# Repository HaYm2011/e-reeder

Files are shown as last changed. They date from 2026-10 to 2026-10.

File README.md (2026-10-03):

# e-reeder
a e-reader... aka chapri kindle

reeder

## Bill of Materials (BOM)

| Item | Component | Vendor | Unit Price (INR) | Qty | Total Price (INR) | Purpose / Notes |
| :--- | :--- | :--- | :---: | :---: | :---: | :--- |
| 1 | [4.3" Serial Interface Electronic Paper Display](https://robocraze.com/products/4-3in-serial-interface-electronic-paper-display) | Robocraze | ₹4,699.00 | 1 | ₹4,699.00 | 800×600 UART e-paper screen |
| 2 | [7Semi ESP32-S3 Dev Board (N8R8, Dual Type-C)](https://robocraze.com/products/7semi-esp32-s3-dev-boardc-1-n8r8-wifi-bluetooth-dual-usb-c-rgb-led) | Robocraze | ₹899.00 | 1 | ₹899.00 | Primary microcontroller (8MB Flash, 8MB PSRAM) |
| 3 | [VL53L0X TOF Laser Distance Sensor](https://robu.in/product/vl53l0x-tof-based-lidar-laser-distance-sensor/) | Robu.in | ₹119.00 | 2 | ₹238.00 | Left & right gesture detection for page turns |
| 4 | [3.7V 2000mAh 18650 Li-Ion Battery](https://robocraze.com/products/3-7v-2000mah-18650-li-ion-battery) | Robocraze | ₹69.00 | 3 | ₹207.00 | Rechargeable battery cells |
| 5 | [18650 3-Cell Holder Without Cover](https://robocraze.com/products/18650-3-cell-holder-charger-without-cover) | Robocraze | ₹33.00 | 1 | ₹33.00 | Series enclosure/leads for 3× 18650 cells |
| 6 | Custom 3D Printed Enclosure:  https://robu.in/product/3d-printing-service1/ | Robocraze 3d-printing service | ₹700.00 | 1 | ₹700.00 | Front & back shell housing |
| **Total** | | | | **9** | **₹6,776.00** | *(Excluding shipping)* |

for the 3d print i have checked the cost of printing it with 0.2 standard quality 20% infil PLA(black): it amounts to ₹700




allreeder
schreeder
pcbreeeder




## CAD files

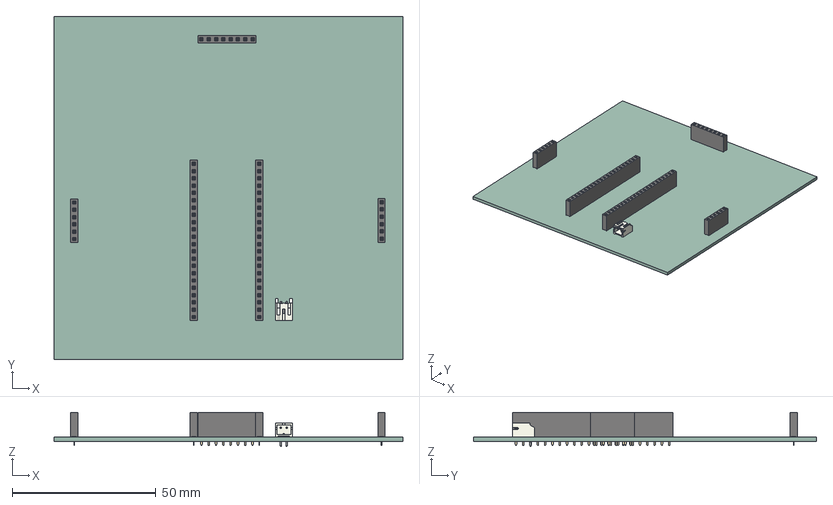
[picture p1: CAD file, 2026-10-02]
e-reeder.step
121.5 x 119.5 x 11.9 mm
PinSocket_1x06_P2.54mm_Vertical x 2
PinSocket_1x08_P2.54mm_Vertical
PinSocket_1x22_P2.54mm_Vertical x 2
JST_PH_S2B-PH-K_1x02_P2.00mm_Horizontal
e-reeder_PCB

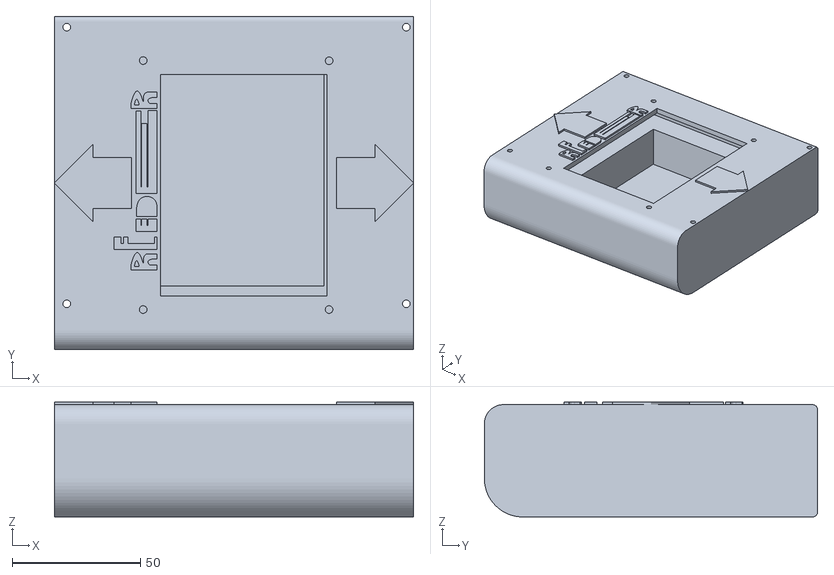
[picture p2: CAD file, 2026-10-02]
reederfinal.stl
140.0 x 130.0 x 44.8

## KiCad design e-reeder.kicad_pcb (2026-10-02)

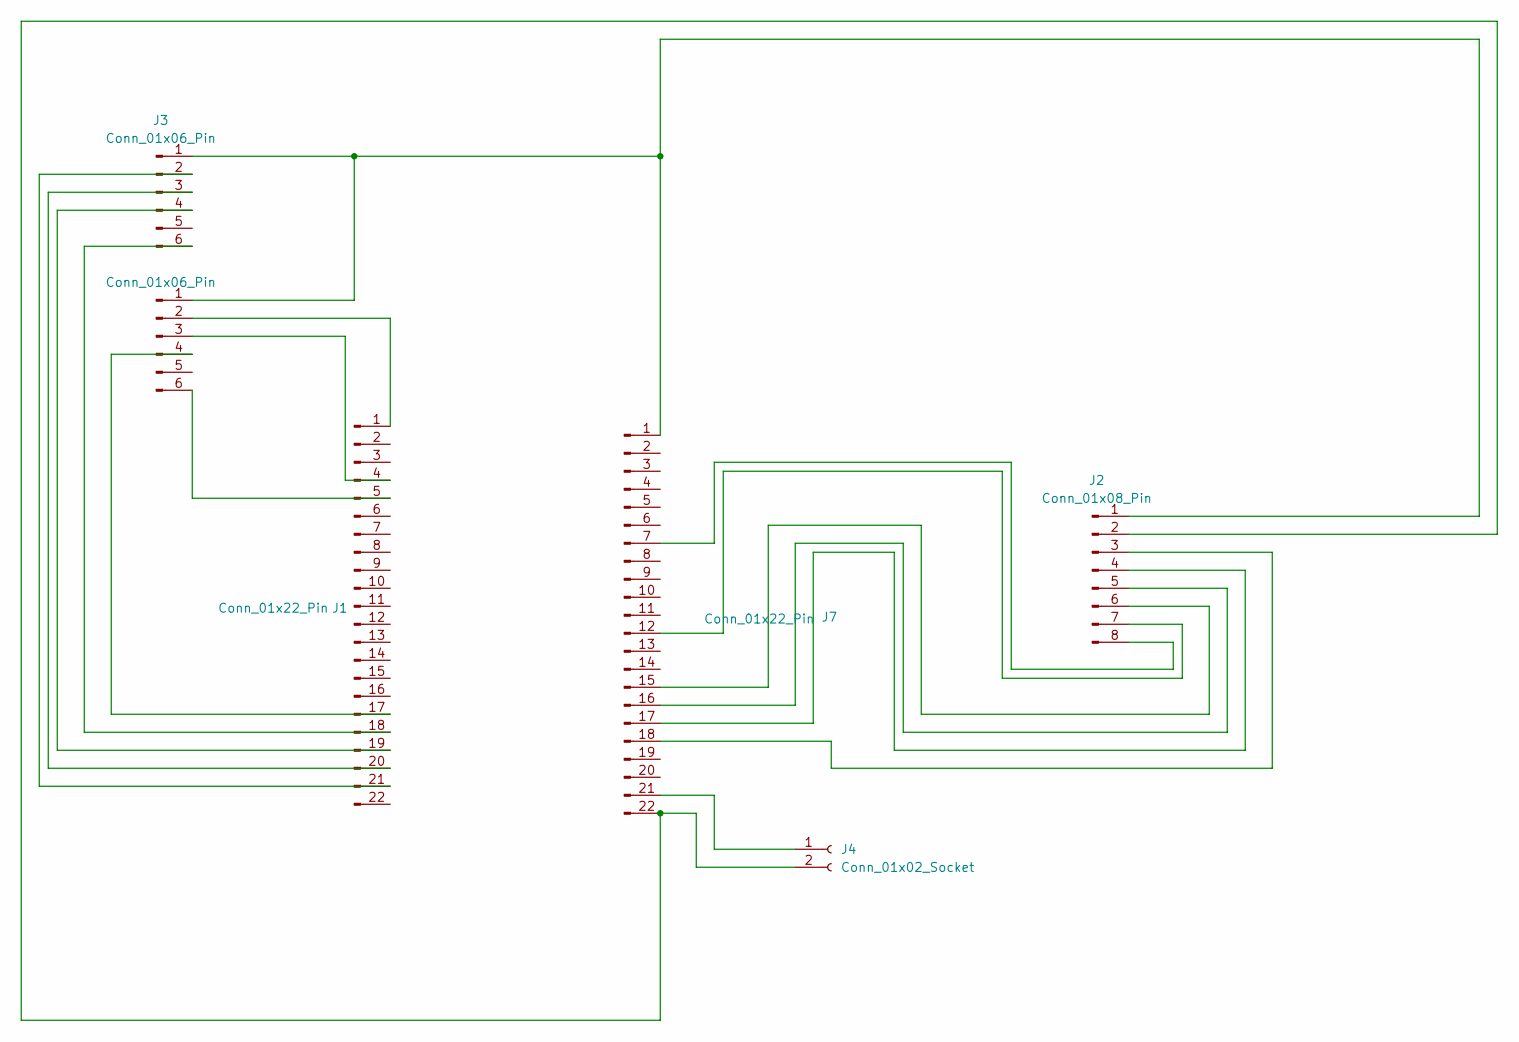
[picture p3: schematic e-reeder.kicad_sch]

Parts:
J1, J7: Conn_01x22_Pin; PinSocket_1x22_P2.54mm_Vertical
J2: Conn_01x08_Pin; PinSocket_1x08_P2.54mm_Vertical
J3, J5: Conn_01x06_Pin; PinSocket_1x06_P2.54mm_Vertical
J4: Conn_01x02_Socket; JST_PH_S2B-PH-K_1x02_P2.00mm_Horizontal

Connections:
unnamed: J1.1, J5.2
unnamed: J1.4, J5.3
unnamed: J1.5, J5.6
unnamed: J1.17, J5.4
unnamed: J1.18, J3.6
unnamed: J1.19, J3.4
unnamed: J1.20, J3.3
unnamed: J1.21, J3.2
unnamed: J2.1, J3.1, J5.1, J7.1
unnamed: J2.2, J4.2, J7.22
unnamed: J2.3, J7.18
unnamed: J2.4, J7.17
unnamed: J2.5, J7.16
unnamed: J2.6, J7.15
unnamed: J2.7, J7.12
unnamed: J2.8, J7.7
unnamed: J4.1, J7.21

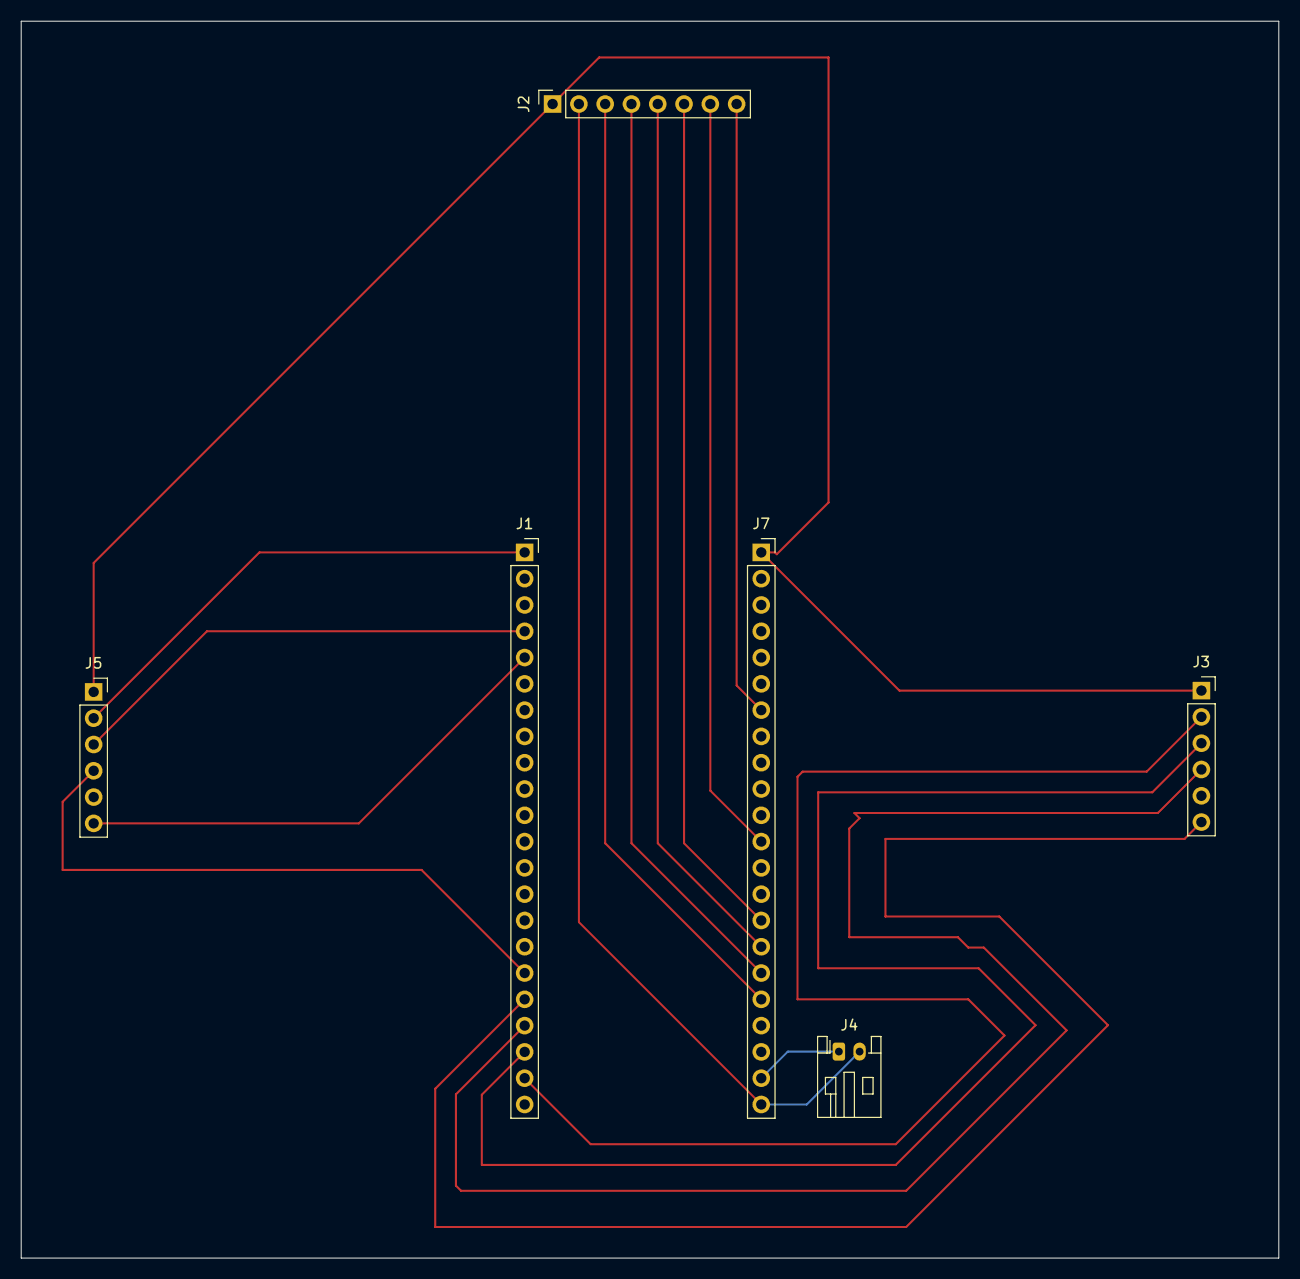
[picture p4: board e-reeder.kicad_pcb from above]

Board: 2 copper layers, 121.5 x 119.5 mm, 6 parts (0 on the bottom side), 17 nets.

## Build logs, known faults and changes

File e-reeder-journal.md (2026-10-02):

# e-reeder

a e-reader... aka chapri kindle

# 2026-10-02: finished up the repo added a BOM

**Total time spent: 0.20 hours**

finished the repo updated the README, added all the project files, the chassis stl. the kicad files and added a BOM 


# 2026-10-02: Finished the chassis of the reeder 

**Total time spent: 1 hour 13 mins**

i finished the design of the chassis of the reeder, i had sm trouble with the battery and i decided ill manually put holes for it while assembling the hardware and the rest of the stuff snaps right in place and use 3mm screws to fix it up together




2026-06-08: made the repository

**Total time spent: 0.20 hours**

made a repo :https://github.com/HaYm2011/e-reeder and added the journal.md im going to add the case step files and the kicad files a bit later


# 2026-06-08: worked a bit on the case

**Total time spent: 0.10 hours**

found a .step file for the batteries and for the sensors
im gonna start with the case for the reeder in the next entry


# 2026-06-04: Started the design

**Total time spent: 1 hour**

got the step file for the pcb ran into a few errors like with the step file and found a good f3d file for the display module . im going to start the design for the chassis in the next entry



# 2026-06-04: added the battery source i forgot about😅

**Total time spent: 0.30 hours**

So i just realised i completely forgot about the battery stuff and i had to go back to the .sch add a JST socket retrace a few copper lines and i think about done with the pcb for real this time





# 2026-06-03: Finished the PCB!!!!!!!!

**Total time spent: 6 hours**

So i finished all the pcb part i was stuck on finding the footprints for all my components for quite a while and then i realised i had to go back to the .sch file for assigning the footprints and i happened to put the male connector footprint instead of the female connector for the esp32 s3 and the sensors. I then did the copper tracing and i had to fix a few overlays in the .sch file and i finally reviewed my progress in the 3d viewer and i had to figure out how to use the measure tool and the move tool at the same time in kicad(i just figured to enter the x,y coords for the components...)

Screenshot 2026-06-03 114855.png

Screenshot 2026-06-03 203839.png

Screenshot 2026-06-03 203854.png

# 2026-05-29: so i finished the pcb schematics (and did a few other stuff)

**Total time spent: 6 hours**

i finished the schematics i changed the e-ink module im gonna be using to:

Waveshare 4.2-inch e-Ink Paper Display Module with SPI Interface:

https://robu.in/product/4-2-inch-e-ink-paper-display-module-with-spi-interface/

this module is essentially the same thing but 0.1 inches lesser than the previous one i selected but this is gonna be easier for me to connect to my esp32 s3.

regarding the pcb schematics i faced quite a few problems since its been a long time since i last used kicad so i forgot that im not supposed to overlay the wires and i spent about a hour rerouting everything and realised that the xshut pins of the VL53L0X TOF Laser Distance Sensors could not be connected to pins like 48 of the esp32 s3 so i rerouted these pins.

i also spent quite a while replacing the older display connections with the newer ones 




# 2026-05-27: research, and making of BOM 

**Total time spent: 5hrs**

So i read about a few other opensource e-reader projects , like this one:

https://github.com/joeycastillo/The-Open-Book

so i realised id like to use a microcontroller for this rather than a micro controller and hence an esp32-s3 for this and a e-ink display i found on robocraze.com :

e-ink module:

https://robocraze.com/products/4-3in-serial-interface-electronic-paper-display?_pos=1&_sid=8128a620e&_ss=r

esp32 s3:

https://robocraze.com/products/7semi-esp32-s3-dev-boardc-1-n8r8-wifi-bluetooth-dual-usb-c-rgb-led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

so i decided im gonna 3d print the frame and add a really compact ToF sensor on each side of the reeder and so when any side detects movement the page is flipped respectively 

VL53L0X TOF Laser Distance Sensor:

https://robu.in/product/vl53l0x-tof-based-lidar-laser-distance-sensor/

for the body of this thing im going to design it and 3d print it



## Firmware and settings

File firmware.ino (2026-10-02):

#include <Wire.h>
#include <Adafruit_VL53L0X.h>

#define I2C_SDA_PIN       8
#define I2C_SCL_PIN       9

#define SENSOR_LEFT_XSHUT  4
#define SENSOR_RIGHT_XSHUT 5

#define EPD_RX_PIN        18
#define EPD_TX_PIN        17
#define EPD_WAKE_PIN      16
#define EPD_RST_PIN       15

HardwareSerial EPD_Serial(1);

#define ADDR_SENSOR_LEFT   0x30
#define ADDR_SENSOR_RIGHT  0x31

Adafruit_VL53L0X sensorLeft  = Adafruit_VL53L0X();
Adafruit_VL53L0X sensorRight = Adafruit_VL53L0X();

#define FRAME_HEADER      0xA5
#define CMD_HANDSHAKE     0x00
#define CMD_SET_BAUD      0x01
#define CMD_READ_BAUD     0x02
#define CMD_SET_MEMORY    0x07
#define CMD_ENTER_STOP    0x08
#define CMD_UPDATE        0x0A
#define CMD_SET_FONT_EN   0x1E
#define CMD_DISP_STRING   0x30
#define CMD_CLEAR         0x2E

#define FONT_ASCII32      0x01
#define FONT_ASCII48      0x02
#define FONT_ASCII64      0x03

#define GESTURE_TRIGGER_MIN_MM  30
#define GESTURE_TRIGGER_MAX_MM  140
#define GESTURE_COOLDOWN_MS     1200

unsigned long lastPageTurnTime = 0;
int currentPage = 0;

const int TOTAL_PAGES = 4;
const char* bookPages[TOTAL_PAGES] = {
  "Project Gutenberg E-Book\n\nChapter 1\nThe cold silence of deep space was interrupted only by the steady hum of life support systems...",
  "Chapter 1 (Cont.)\n\nHe checked the navigation telemetry. The trajectory remained locked towards the distant orbital gate.",
  "Chapter 2\n\nThe sensors pinged a rhythmic anomaly 200 kilometers off the port bow. Something was tracking their velocity profile.",
  "End of Preview.\n\nSwipe left to return to previous pages or restart the demonstration."
};

void epdSendPacket(uint8_t cmd, const uint8_t *payload, uint16_t length) {
  uint16_t frameLen = 1 + 2 + 1 + length + 4 + 1;
  uint8_t buffer[frameLen];
  
  buffer[0] = FRAME_HEADER;
  buffer[1] = (frameLen >> 8) & 0xFF;
  buffer[2] = frameLen & 0xFF;
  buffer[3] = cmd;
  
  for (uint16_t i = 0; i < length; i++) {
    buffer[4 + i] = payload[i];
  }
  
  uint16_t tailIndex = 4 + length;
  buffer[tailIndex++] = 0xCC;
  buffer[tailIndex++] = 0x33;
  buffer[tailIndex++] = 0xC3;
  buffer[tailIndex++] = 0x3C;
  
  uint8_t parity = 0;
  for (uint16_t i = 0; i < tailIndex; i++) {
    parity ^= buffer[i];
  }
  buffer[tailIndex] = parity;
  
  EPD_Serial.write(buffer, frameLen);
  EPD_Serial.flush();
  delay(20);
}

void epdClearScreen() {
  epdSendPacket(CMD_CLEAR, NULL, 0);
}

void epdRefresh() {
  epdSendPacket(CMD_UPDATE, NULL, 0);
}

void epdSetEnFont(uint8_t font) {
  uint8_t data[1] = { font };
  epdSendPacket(CMD_SET_FONT_EN, data, 1);
}

void epdDisplayString(int16_t x, int16_t y, const char *str) {
  uint16_t strLen = strlen(str);
  uint16_t payloadLen = 4 + strLen + 1;
  uint8_t payload[payloadLen];
  
  payload[0] = (x >> 8) & 0xFF;
  payload[1] = x & 0xFF;
  payload[2] = (y >> 8) & 0xFF;
  payload[3] = y & 0xFF;
  
  memcpy(&payload[4], str, strLen);
  payload[4 + strLen] = 0x00;
  
  epdSendPacket(CMD_DISP_STRING, payload, payloadLen);
}

void renderCurrentPage() {
  Serial.printf("Rendering Page %d of %d...\n", currentPage + 1, TOTAL_PAGES);
  
  epdClearScreen();
  epdSetEnFont(FONT_ASCII32);
  
  char headerBuf[32];
  snprintf(headerBuf, sizeof(headerBuf), "--- OpenBook S3 | Page %d/%d ---", currentPage + 1, TOTAL_PAGES);
  epdDisplayString(40, 30, headerBuf);
  
  char tempBuffer[512];
  strncpy(tempBuffer, bookPages[currentPage], sizeof(tempBuffer));
  
  char *line = strtok(tempBuffer, "\n");
  int yOffset = 100;
  
  while (line != NULL && yOffset < 540) {
    epdDisplayString(40, yOffset, line);
    yOffset += 45;
    line = strtok(NULL, "\n");
  }
  
  epdRefresh();
}

void setupToFSensors() {
  pinMode(SENSOR_LEFT_XSHUT, OUTPUT);
  pinMode(SENSOR_RIGHT_XSHUT, OUTPUT);
  
  digitalWrite(SENSOR_LEFT_XSHUT, LOW);
  digitalWrite(SENSOR_RIGHT_XSHUT, LOW);
  delay(20);
  
  digitalWrite(SENSOR_LEFT_XSHUT, HIGH);
  delay(20);
  if (!sensorLeft.begin(ADDR_SENSOR_LEFT, false, &Wire)) {
    Serial.println("Error: Failed to init Left VL53L0X!");
  } else {
    Serial.println("Left VL53L0X active at 0x30");
  }
  
  digitalWrite(SENSOR_RIGHT_XSHUT, HIGH);
  delay(20);
  if (!sensorRight.begin(ADDR_SENSOR_RIGHT, false, &Wire)) {
    Serial.println("Error: Failed to init Right VL53L0X!");
  } else {
    Serial.println("Right VL53L0X active at 0x31");
  }
}

void setup() {
  Serial.begin(115200);
  delay(1000);
  Serial.println("Starting ESP32-S3 E-Reader firmware...");

  pinMode(EPD_WAKE_PIN, OUTPUT);
  pinMode(EPD_RST_PIN, OUTPUT);
  digitalWrite(EPD_WAKE_PIN, HIGH);
  
  digitalWrite(EPD_RST_PIN, LOW);
  delay(50);
  digitalWrite(EPD_RST_PIN, HIGH);
  delay(200);

  EPD_Serial.begin(115200, SERIAL_8N1, EPD_RX_PIN, EPD_TX_PIN);

  Wire.begin(I2C_SDA_PIN, I2C_SCL_PIN, 400000);
  setupToFSensors();

  renderCurrentPage();
}

void loop() {
  VL53L0X_RangingMeasurementData_t measureLeft;
  VL53L0X_RangingMeasurementData_t measureRight;

  sensorLeft.rangingTest(&measureLeft, false);
  sensorRight.rangingTest(&measureRight, false);

  uint16_t distLeft = (measureLeft.RangeStatus != 4) ? measureLeft.RangeMilliMeter : 9999;
  uint16_t distRight = (measureRight.RangeStatus != 4) ? measureRight.RangeMilliMeter : 9999;

  unsigned long currentMillis = millis();

  if (currentMillis - lastPageTurnTime > GESTURE_COOLDOWN_MS) {
    if (distRight >= GESTURE_TRIGGER_MIN_MM && distRight <= GESTURE_TRIGGER_MAX_MM) {
      if (currentPage < TOTAL_PAGES - 1) {
        Serial.printf("Right gesture detected (%d mm). Next Page.\n", distRight);
        currentPage++;
        lastPageTurnTime = currentMillis;
        renderCurrentPage();
      }
    }
    else if (distLeft >= GESTURE_TRIGGER_MIN_MM && distLeft <= GESTURE_TRIGGER_MAX_MM) {
      if (currentPage > 0) {
        Serial.printf("Left gesture detected (%d mm). Previous Page.\n", distLeft);
        currentPage--;
        lastPageTurnTime = currentMillis;
        renderCurrentPage();
      }
    }
  }

  delay(60);
}

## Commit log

2026-10-02 added the chassis stl.
    [reederfinal.stl]
2026-10-02 Clarify 3D print file name in README
    Updated README to specify the 3D print file name for the body design.
2026-10-02 Add images for 3D printed body
    Added images for the 3D printed body in README.
2026-10-02 added pcb files
    [e-reeder.kicad_pcb, e-reeder.kicad_sch, e-reeder.step]
2026-10-02 Create BOM
2026-10-02 Update BOM
2026-10-02 Fix formatting in BOM file
2026-10-02 Add custom 3D printed enclosure to BOM
2026-10-02 Update BOM with 3D printing cost and image
    Added details about 3D printing cost and included an image.
2026-10-02 Fix link format for 3D Printed Enclosure entry
    Updated the link for the Custom 3D Printed Enclosure in BOM.md.
2026-10-02 Add firmware for ESP32-S3 E-Reader with sensors
2026-10-03 Update 3D print cost details in README
    Clarified the cost of 3D printing in the README.
2026-10-10 Add BOM.csv file
2026-10-10 Convert BOM to CSV format
    Converted BOM from markdown to CSV format and removed unnecessary content.
